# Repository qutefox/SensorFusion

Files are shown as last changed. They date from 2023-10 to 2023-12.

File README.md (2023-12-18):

# Board:
Top | Bottom
--- | ---
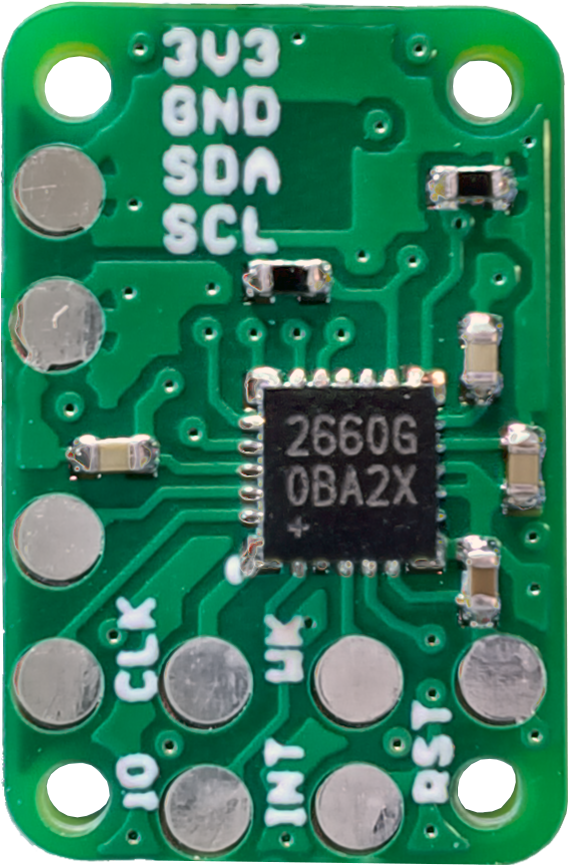
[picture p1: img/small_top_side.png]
Board top side
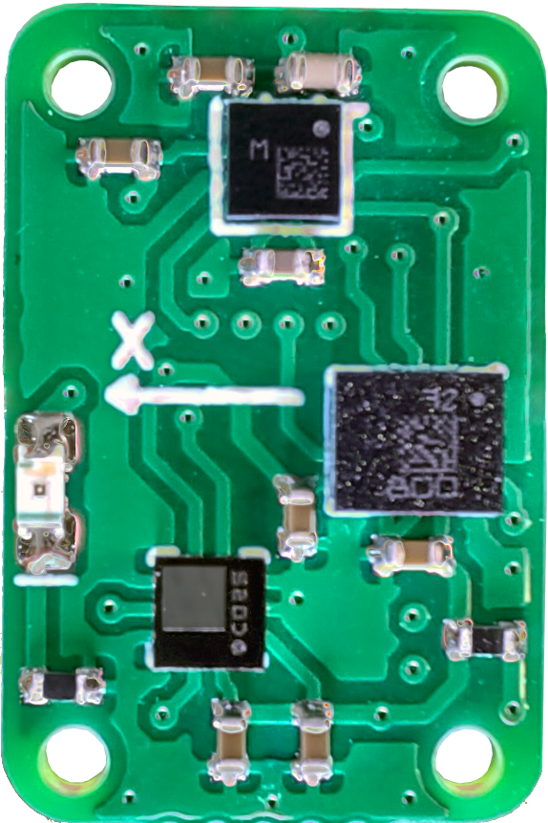
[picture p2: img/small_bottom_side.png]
Board bottom side
 | 

# TODOs:
- calibrate
- host interrupt pin function
- wake pin function
- remove all debug serial print lines and uninit debug serial port
- somehow make automated tests? or at least manual tests with some references
- add some documenatation: register map, usage info

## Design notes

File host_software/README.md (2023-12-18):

# Read out sensor fusion data from host

## Software Prerequisites
- python3

## Hardware Prerequisites
- board with circuitpython (or you can write your own arduino library to use other boards)

## Wiring
Connect your host board to the sensor fusion board via i2c.
Connect your host board to the windows PC via serial (in my case I use the built in circuitpython REPL).

I used Unexpected Maker's PROS3 board (ESP32-S3):

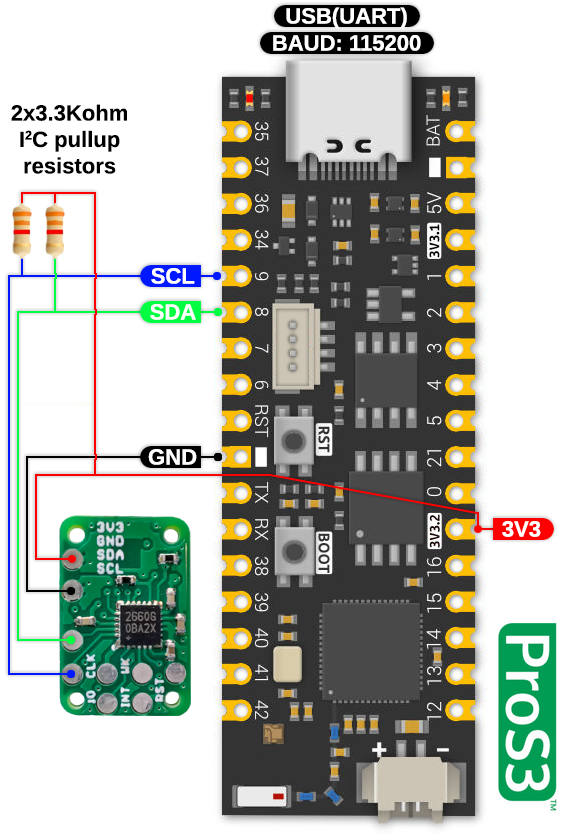
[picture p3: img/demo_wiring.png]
Demo wiring

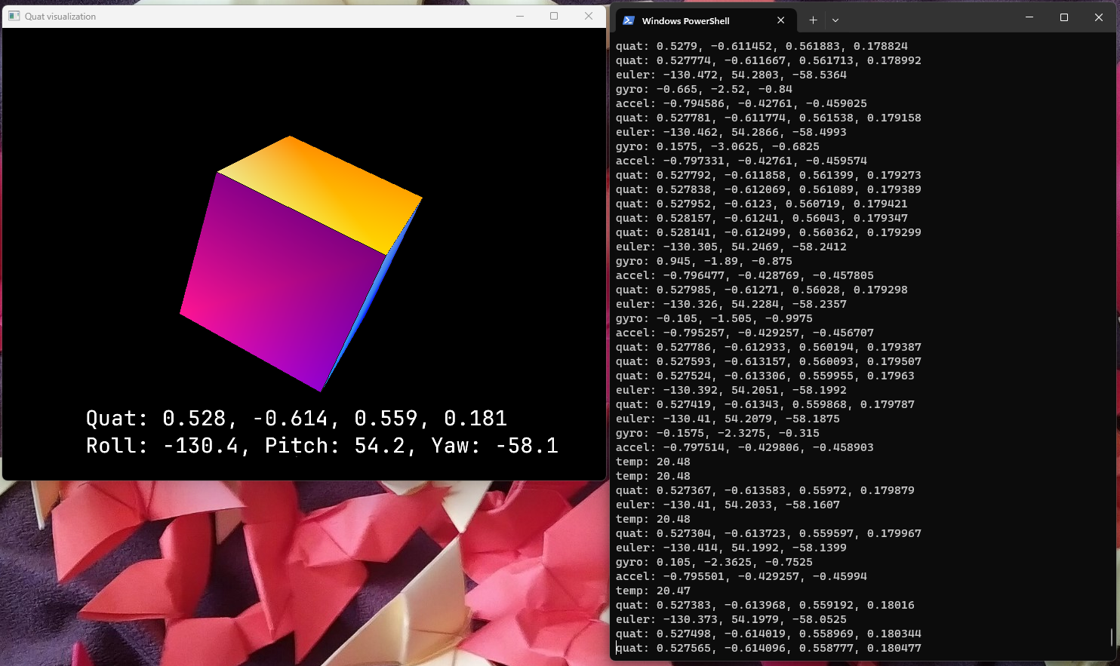
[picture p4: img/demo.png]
Demo


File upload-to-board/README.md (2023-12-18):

# Upload to board

## Software Prerequisites
- python3
- [SEGGER JLink](https://www.segger.com/downloads/jlink/)

## Hardware Prerequisites
- Programmer (Ebay search words: "J-Link OB ARM Debugger Programmer Downloader V8 SWD")
- MAX32660 sensor board
- Jumper wires
- Optional, Serial to USB converter (3.3V) to print out debugging messages

Programmer | Serial to USB 
--- | ---
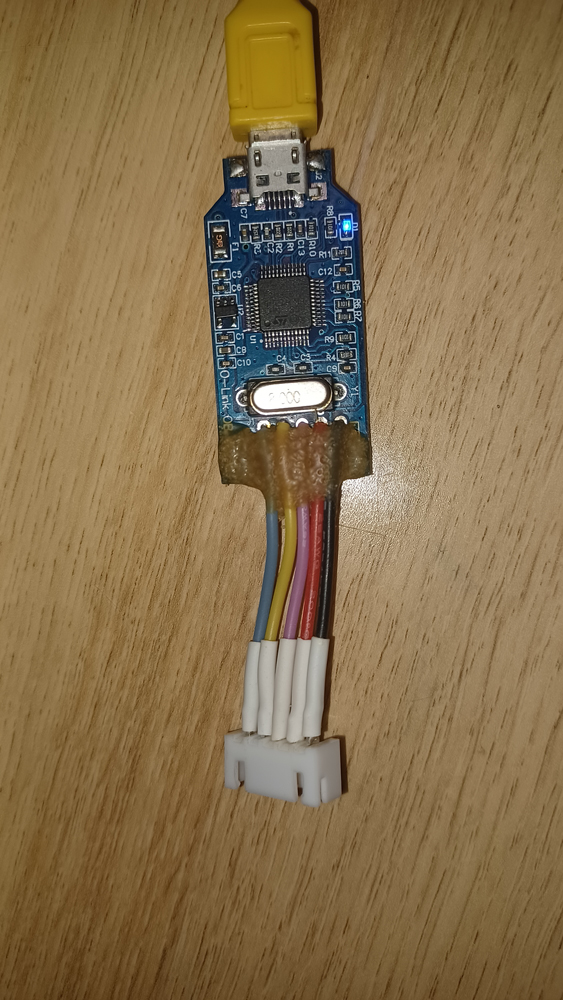
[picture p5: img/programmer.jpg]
Programmer
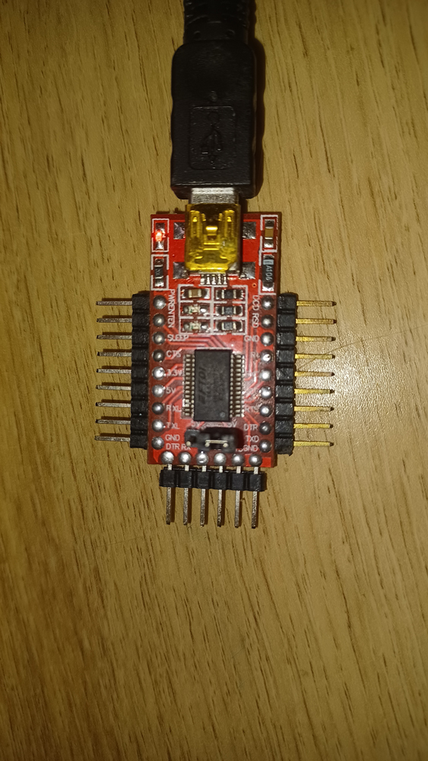
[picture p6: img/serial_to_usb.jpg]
Serial to USB
 | 

Top | Side | Bottom
--- | --- | ---
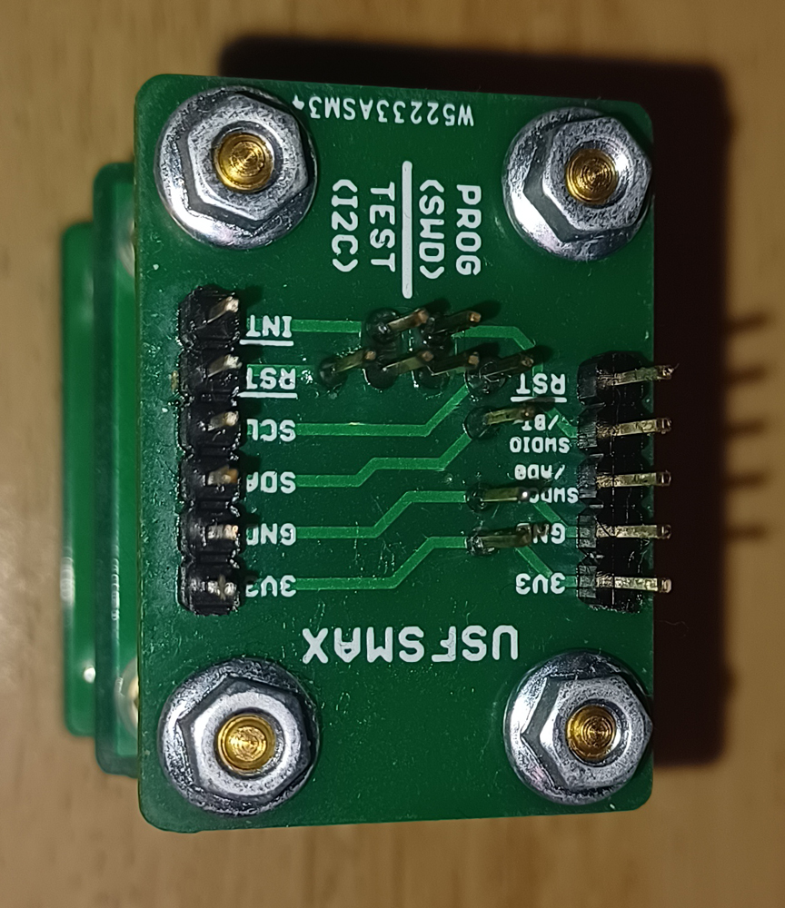
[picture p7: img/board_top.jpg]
Board top
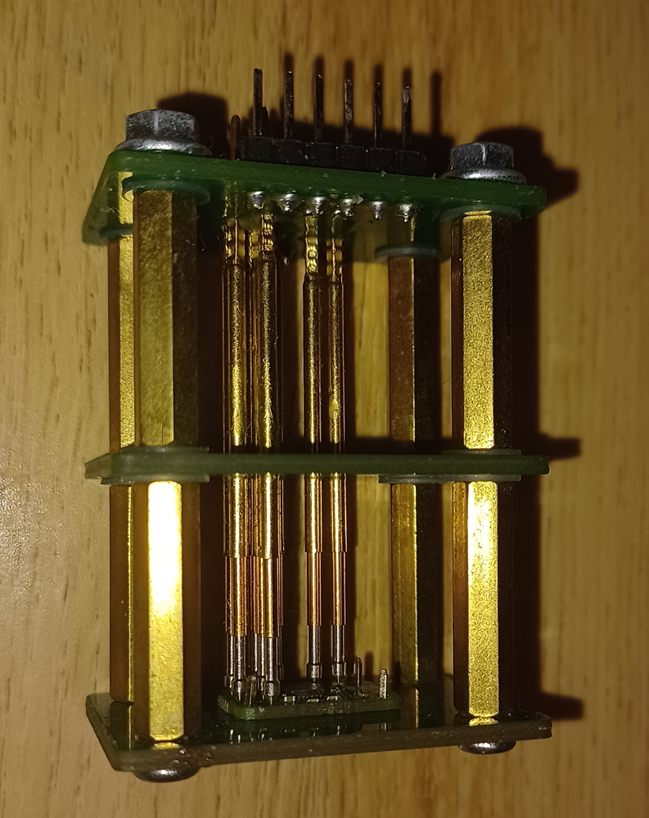
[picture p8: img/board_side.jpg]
Board side
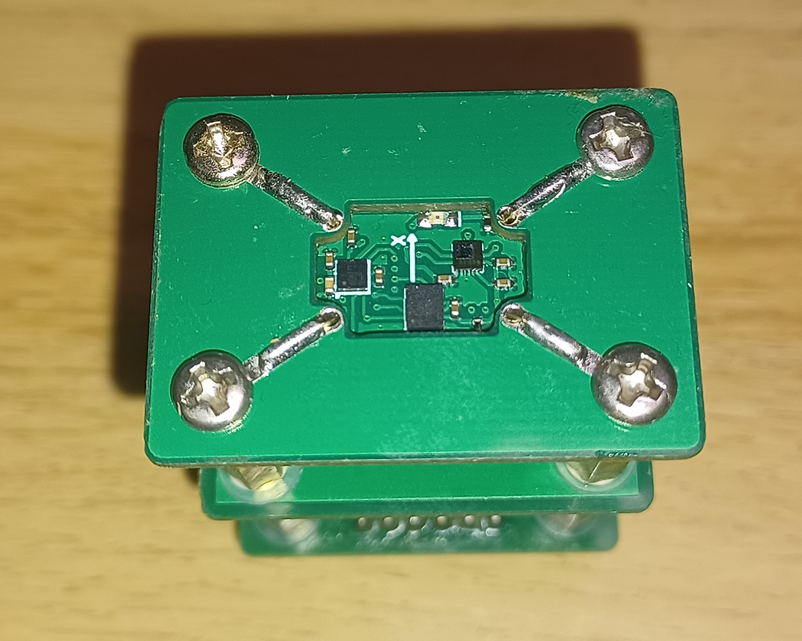
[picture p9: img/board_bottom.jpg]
Board bottom
 |  | 

## Programmer Wiring
Board      | Programmer
-----------|-----------
GND        | GND
3.3V       | 3.3V
SWDCLK/AD0 | SWCLK
SWDIO/BT   | SWDIO
RST        | RST

Programmer setup | Programmer connection | Board connection
--- | --- | ---
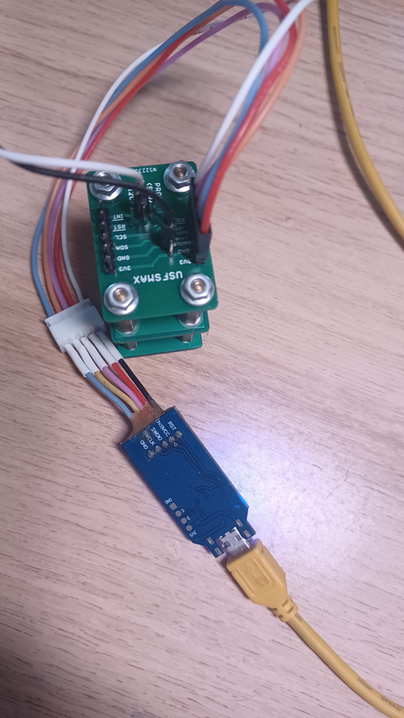
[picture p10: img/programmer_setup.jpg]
Programmer setup
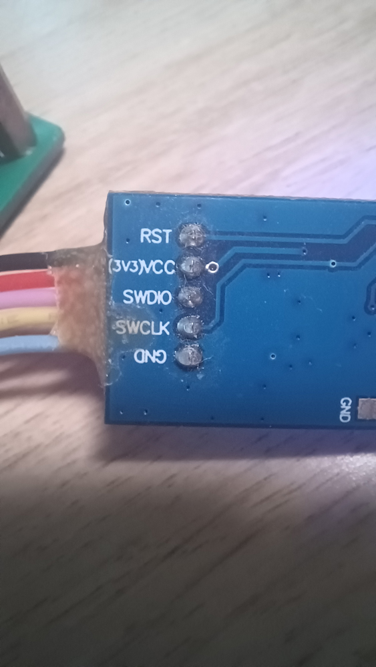
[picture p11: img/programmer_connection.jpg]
Programmer connection
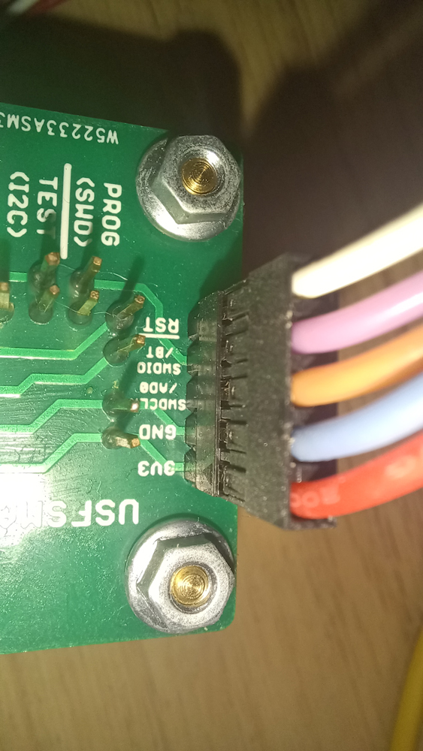
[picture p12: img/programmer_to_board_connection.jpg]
Programmer to board connection
 |  | 

## Serial Wiring (optional)
Board | Serial to USB
------|--------------
GND   | GND
INT   | RX

Serial setup | Serial connection | Board connection
--- | --- | ---
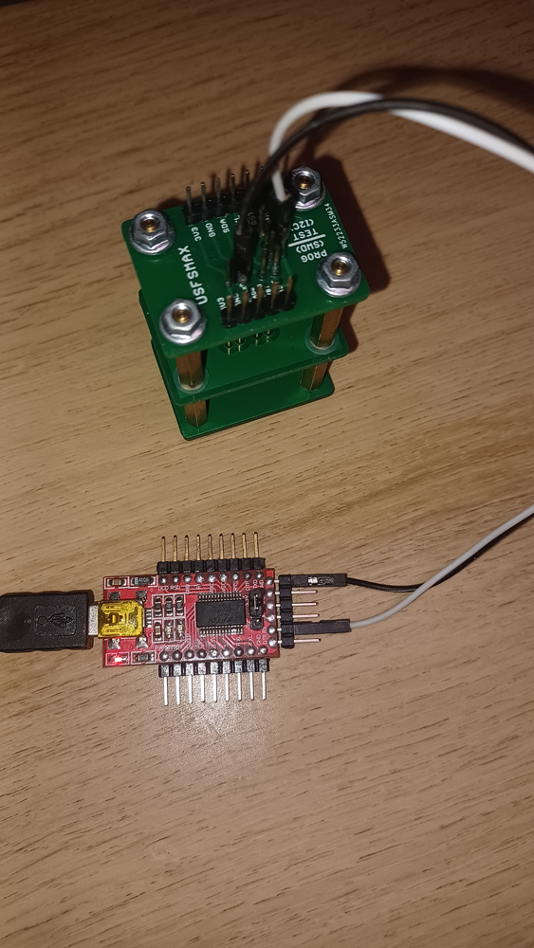
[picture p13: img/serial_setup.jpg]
Serial setup
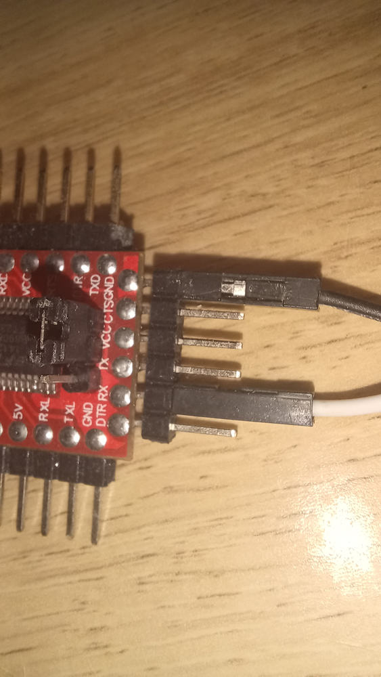
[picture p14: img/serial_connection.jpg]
Serial connection
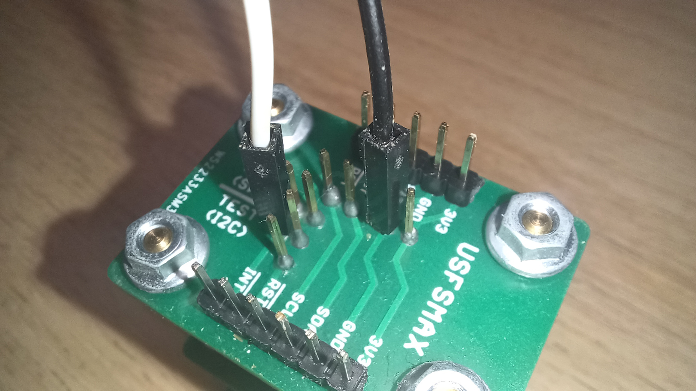
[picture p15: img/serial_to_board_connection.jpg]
Serial to board connection
 |  | 

## Upload
- Wire up the programmer to the board
- Open command line and run command:
```
python path/to/jlink_upload.py
```

## What the script does
- Opens and SWD connection
- Executes commands from file command_file.jlink
	* Uploads the built elf file to the board
	* Resets the board
	* Starts the board
	* Closes the SWD connection

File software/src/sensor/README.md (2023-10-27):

# Sensor driver usage
There are tons of examples on how to use these sensor drivers at https://github.com/STMicroelectronics/STMems_Standard_C_drivers

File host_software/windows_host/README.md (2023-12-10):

# Cube visualisation

To run use command:
```
python windows_host_with_cube_visualisation.py
```

Demo

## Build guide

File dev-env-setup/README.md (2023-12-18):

# Development environment setup guide

For a full guide please visit: https://analog-devices-msdk.github.io/msdk/USERGUIDE/#installation
Further down I will focus on how I setup my own dev environment.

## Visual Studio Code
I use Visual Studio Code as my IDE.
You can download and install it from: https://code.visualstudio.com/download
After completing the Visual Studio Code installation you need to start the IDE and navigate to the extensions.
- Install the [Microsoft C/C++ extension](https://marketplace.visualstudio.com/items?itemName=ms-vscode.cpptools)
- Install the [Cortex-Debug extension](https://marketplace.visualstudio.com/items?itemName=marus25.cortex-debug)
- Later on we will come back and tell Visual Studi Code where we installed the Maxim Micros SDK

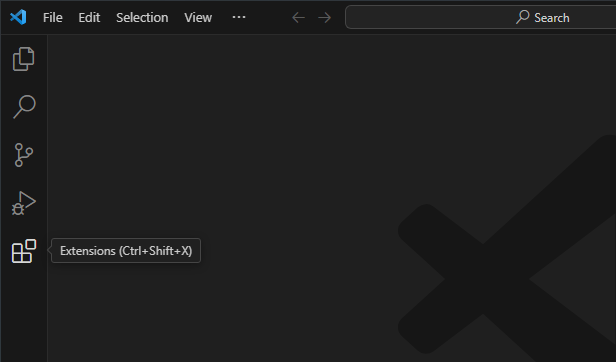
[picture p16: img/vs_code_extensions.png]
Visual Studio Code extensions

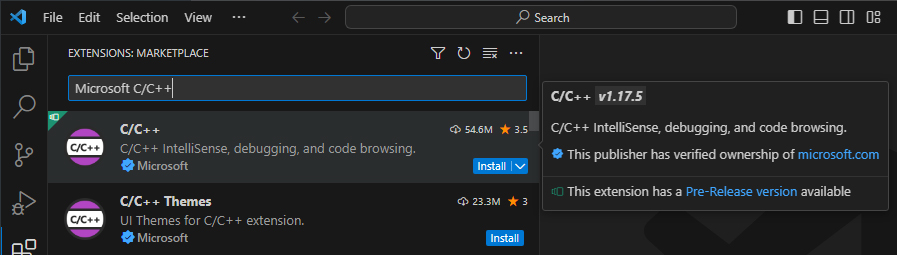
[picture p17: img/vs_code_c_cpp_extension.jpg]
Visual Studio Code C/C++ extension

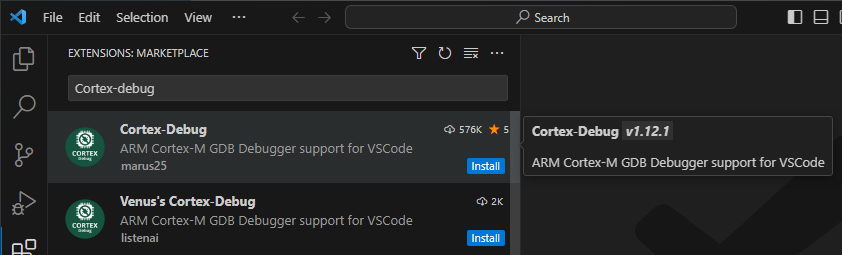
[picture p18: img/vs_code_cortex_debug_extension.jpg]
Visual Studio Code Cortex-Debug extension


## Maxim Micros SDK
You can find documentation, resources, tool, etc.. at: https://www.analog.com/en/products/max32660.html

In the Tools and Simulation section you can find the Maxim Micros SDK download link(s).
Here I give the link to the latest version I can find during writing this guide:
[Maxim Micros SDK (Windows), 1.0.1](https://www.analog.com/en/design-center/evaluation-hardware-and-software/software/software-download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)

During the Maxim Micros SDK (Windows) installation on the component selection screen make sure that "Visual Studio Code Support" is checked.

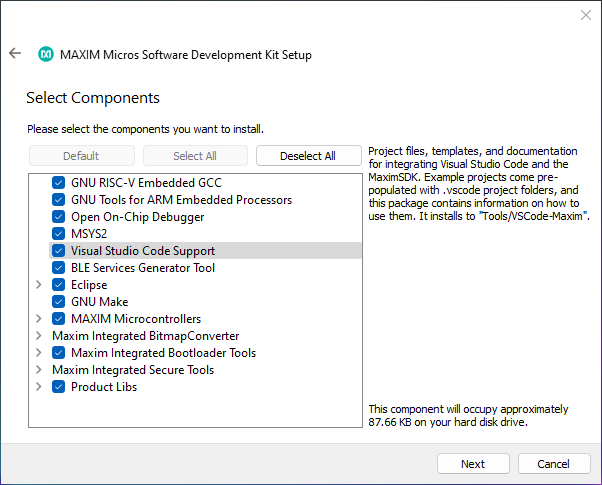
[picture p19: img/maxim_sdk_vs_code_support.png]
Visual Studio Code support


When the installation finishes a popup will appear that will take you to the readme file of the Visual Studio Code Support github page: https://github.com/Analog-Devices-MSDK/VSCode-Maxim/blob/main/README.md

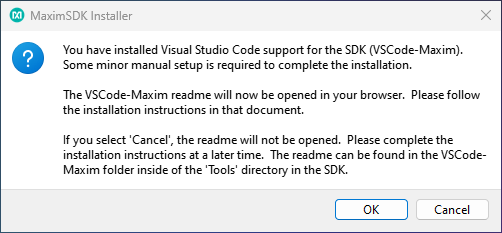
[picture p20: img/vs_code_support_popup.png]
Visual Studio Code support popup


## Setting the "MAXIM_PATH" in your VS Code settings
- Open Visual Studio Code
- Press Ctrl + Shift + P
- In the popup type "Preferences: Open User Settings (JSON)"
- Add a new entry called "MAXIM_PATH" with the path of your MaximSDK installation path. Only use forward slash characters.

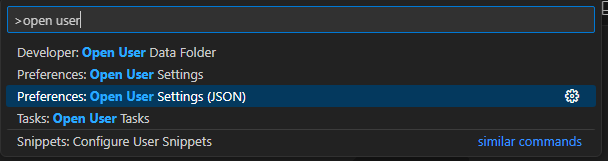
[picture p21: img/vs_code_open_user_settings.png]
Visual Studio Code user settings

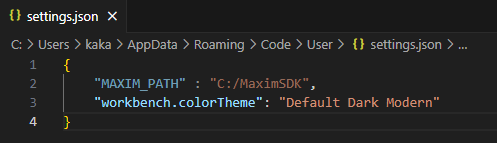
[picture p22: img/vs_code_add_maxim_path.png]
Visual Studio Code maxim path


## How to build
- Open Visual Studio Code
- Open the project
- Press Ctrl + Shift + B
- From the popup select build (or clean and the build).

## How to update the Maxim SDK
You can run the MaintenanceTool.exe which will automatically guide you through the update.

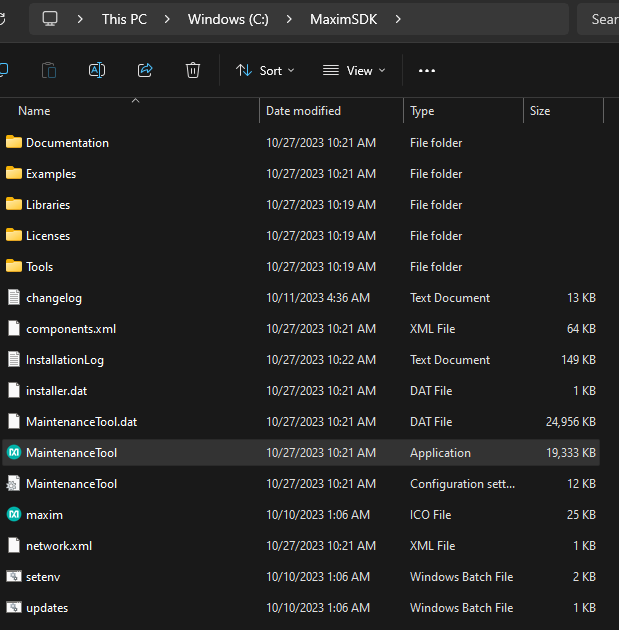
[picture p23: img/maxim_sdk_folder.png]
Maxim Micros SDK Folder


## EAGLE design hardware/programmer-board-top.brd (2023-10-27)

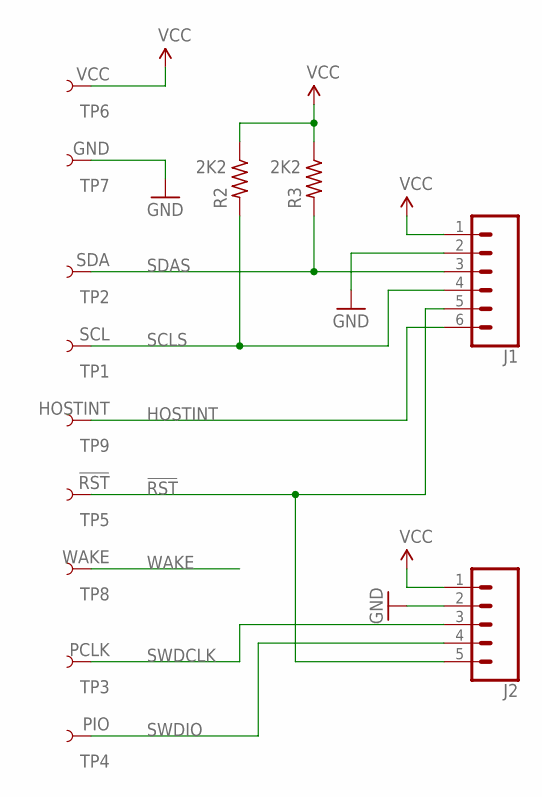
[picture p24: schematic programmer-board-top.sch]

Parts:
J1: CONN_06NO_SILK_FEMALE_PTH; 1X06_NO_SILK
J2: CONN_05NO_SILK; 1X05_NO_SILK
R2, R3: 2K2; R0402_B
TP1: SCL; PAD.03X.06
TP2: SDA; PAD.03X.06
TP3: PCLK; PAD.03X.06
TP4: PIO; PAD.03X.06
TP5: !RST; PAD.03X.06
TP6: VCC; PAD.03X.06
TP7: GND; PAD.03X.06
TP8: WAKE; PAD.03X.06
TP9: HOSTINT; PAD.03X.06

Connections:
!RST: J1.5, J2.5, TP5.1
GND: J1.2, J2.2, TP7.1
HOSTINT: J1.6, TP9.1
SCLS: J1.4, R2.2, TP1.1
SDAS: J1.3, R3.2, TP2.1
SWDCLK: J2.3, TP3.1
SWDIO: J2.4, TP4.1
VCC: J1.1, J2.1, R2.1, R3.1, TP6.1
WAKE: TP8.1

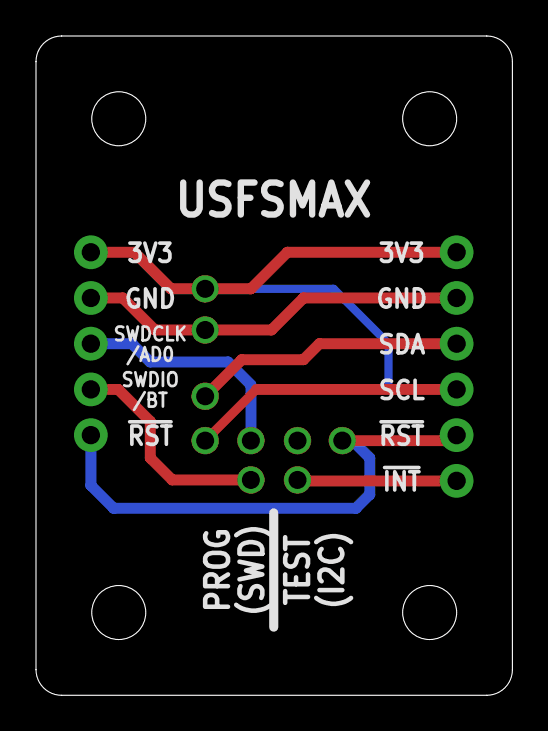
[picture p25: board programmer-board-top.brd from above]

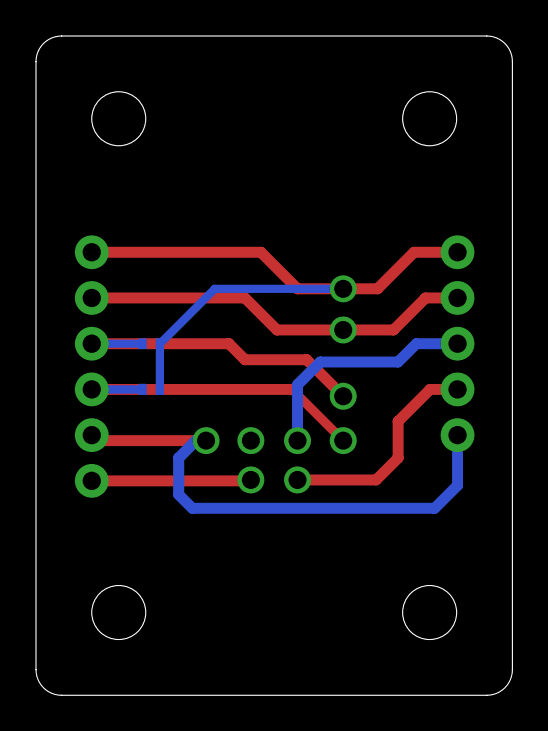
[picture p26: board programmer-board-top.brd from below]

Board: 2 copper layers, 26.5 x 36.6 mm, 13 parts (2 on the bottom side), 8 nets.

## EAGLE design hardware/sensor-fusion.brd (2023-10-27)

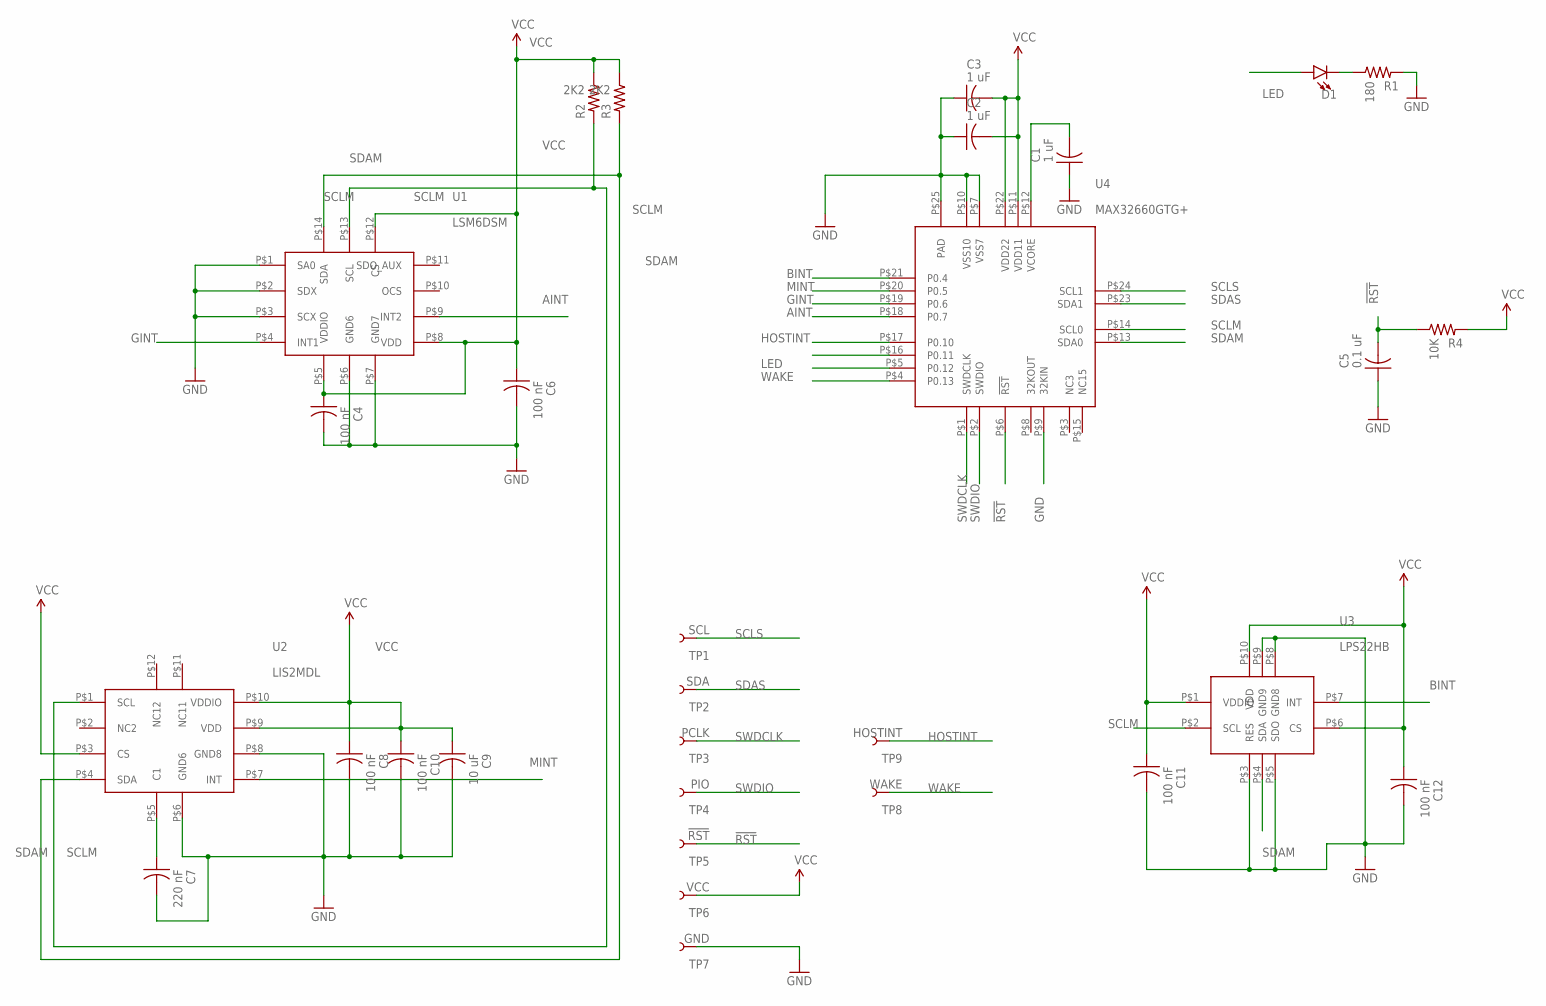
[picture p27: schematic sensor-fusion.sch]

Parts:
C1, C2, C3: 1 uF; C0402_B
C4, C6, C8, C10, C11, C12: 100 nF; C0402_B
C5: 0.1 uF; C0402_B
C7: 220 nF; C0402_B
C9: 10 uF; C0402_B
D1: LED0603; LED-0603
R1: 180; R0402_B
R2, R3: 2K2; R0402_B
R4: 10K; R0402_B
TP1: SCL; PAD.03X.06
TP2: SDA; PAD.03X.06
TP3: PCLK; PAD.03X.06
TP4: PIO; PAD.03X.06
TP5: !RST; PAD.03X.06
TP6: VCC; PAD.03X.06
TP7: GND; PAD.03X.06
TP8: WAKE; PAD.03X.06
TP9: HOSTINT; PAD.03X.06
U1: LSM6DSM
U2: LIS2MDL
U3: LPS22HB
U4: MAX32660GTG+

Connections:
!RST: C5.2, R4.1, TP5.1, U4.P$6 (!RST)
AINT: U1.P$9 (INT2), U4.P$18 (P0.7)
BINT: U3.P$7 (INT), U4.P$21 (P0.4)
GINT: U1.P$4 (INT1), U4.P$19 (P0.6)
GND: C1.1, C2.1, C3.1, C4.2, C5.1, C6.2, C7.2, C8.2, C9.2, C10.2, C11.2, C12.2, R1.2, TP7.1, U1.P$1 (SA0), U1.P$2 (SDX), U1.P$3 (SCX), U1.P$6 (GND6), U1.P$7 (GND7), U2.P$6 (GND6), U2.P$8 (GND8), U3.P$3 (RES), U3.P$5 (SDO), U3.P$8 (GND8), U3.P$9 (GND9), U4.P$7 (VSS7), U4.P$9 (32KIN), U4.P$10 (VSS10), U4.P$25 (PAD)
HOSTINT: TP9.1, U4.P$17 (P0.10)
LED: D1.A, U4.P$5 (P0.12)
MINT: U2.P$7 (INT), U4.P$20 (P0.5)
unnamed: C7.1, U2.P$5 (C1)
unnamed: C1.2, U4.P$12 (VCORE)
unnamed: D1.C, R1.1
OCS: U1.P$10 (OCS)
SCLM: R2.2, U1.P$13 (SCL), U2.P$1 (SCL), U3.P$2 (SCL), U4.P$14 (SCL0)
SCLS: TP1.1, U4.P$24 (SCL1)
SDAM: R3.2, U1.P$14 (SDA), U2.P$4 (SDA), U3.P$4 (SDA), U4.P$13 (SDA0)
SDAS: TP2.1, U4.P$23 (SDA1)
SDO_AUX: U1.P$11 (SDO_AUX)
SWDCLK: TP3.1, U4.P$1 (SWDCLK)
SWDIO: TP4.1, U4.P$2 (SWDIO)
VCC: C2.2, C3.2, C4.1, C6.1, C8.1, C9.1, C10.1, C11.1, C12.1, R2.1, R3.1, R4.2, TP6.1, U1.P$5 (VDDIO), U1.P$8 (VDD), U1.P$12 (CS), U2.P$3 (CS), U2.P$9 (VDD), U2.P$10 (VDDIO), U3.P$1 (VDDIO), U3.P$6 (CS), U3.P$10 (VDD), U4.P$11 (VDD11), U4.P$22 (VDD22)
WAKE: TP8.1, U4.P$4 (P0.13)

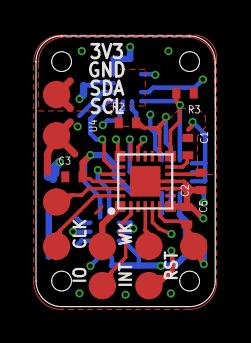
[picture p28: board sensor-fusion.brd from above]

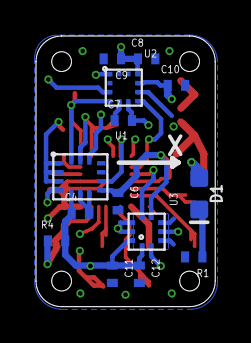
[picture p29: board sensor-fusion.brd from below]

Board: 4 copper layers, 10.0 x 15.0 mm, 30 parts (14 on the bottom side), 19 nets.

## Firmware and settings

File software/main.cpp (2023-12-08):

#include <stdio.h>
#include <exception>

#include "mxc_device.h"
#include "mxc_delay.h"
#include "mxc_errors.h"
#include "lp.h"
#include "uart.h"

#include "src/sensor_fusion_board.h"
#include "src/processor_logic/controller.h"

#include "src/debug_print.h"

// https://analog-devices-msdk.github.io/msdk/Libraries/PeriphDrivers/Documentation/MAX32660/

int main()
{

#ifdef ENABLE_DEBUG_PRINT
    MXC_UART_Init(MXC_UART_GET_UART(CONSOLE_UART), CONSOLE_BAUD, MAP_A);
#endif

	debug_print("\n\nMAX32660 started with debug info.\n");

	SensorFusionBoard* board = SensorFusionBoard::get_instance();

	debug_print("About to init board.\n");

	int board_err = board->begin();
	if (board_err != E_NO_ERROR)
	{
		debug_print("Failed to initialize board: %d.\n", board_err);
	}
	else
	{
		debug_print("Board successfully initialized.\n");
	}

	Controller* controller = Controller::get_instance();

	__enable_irq();

	while (true)
	{
		if (board->can_go_sleep())
		{
			board->prepare_for_sleep();
			MXC_LP_EnterSleepMode();
			// MXC_LP_EnterDeepSleepMode();
		}

		// Handle sensor interrupt(s).
		board->handle_sensor_interrupts();

		// Controller update.
		controller->handle_wakeup();
	}

    return E_NO_ERROR;
}

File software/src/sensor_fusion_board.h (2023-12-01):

#pragma once

#include "mxc_errors.h"

#include "src/storage/flash_interface.h"
#include "src/io/digital_input_pin_interface.h"
#include "src/io/digital_output_pin_interface.h"
#include "src/io/i2c_slave_interface.h"
#include "src/sensor/sensor_interface.h"

#define CONSOLE_UART 1 // UART instance to use for console
#define CONSOLE_BAUD 115200 // Console baud rate

#define I2C_SLAVE 1
#define I2C_SLAVE_SPEED 400000 // 400 kbit/s (aka i2c fast speed)
#define I2C_SLAVE_ADDR 0x51

#define I2C_MASTER 0
#define I2C_MASTER_SPEED 400000 // 400 kbit/s (aka i2c fast speed)
#define I2C_MASTER_CLOCK_STRETCHING 0

#define LPS22HB_I2C_ADDR 0x5C
#define LSM6DSM_I2C_ADDR 0x6A
#define LIS2MDL_I2C_ADDR 0x1E

#define SWDIO_MASK MXC_GPIO_PIN_0 // We only use it after startup. We could use it for something later on.
#define AD0_MASK__SWDCLK_MASK MXC_GPIO_PIN_1 // Free pin after startup. We could use it for something.
#define BARO_INT_MASK MXC_GPIO_PIN_4
#define MAG_INT_MASK MXC_GPIO_PIN_5
#define INERTIAL_INT2_MASK MXC_GPIO_PIN_6
#define INERTIAL_INT1_MASK MXC_GPIO_PIN_7
#define HOSTINT_PIN_MASK MXC_GPIO_PIN_10
#define LED_PIN_MASK MXC_GPIO_PIN_12
#define WAKE_PIN_MASK MXC_GPIO_PIN_13

class SensorFusionBoard
{
private:
    static SensorFusionBoard* instance;
    static uint32_t lock;

    storage::FlashInterface* flash = nullptr;
    io::DigitalOutputPinInterface* led_pin = nullptr;
    io::DigitalOutputPinInterface* host_interrupt_pin = nullptr;
    io::DigitalInputPinInterface* i2c_slave_address_select_pin = nullptr;
    io::DigitalInputPinInterface* barometer_int_pin = nullptr;
    io::DigitalInputPinInterface* inertial_int1_pin = nullptr;
    io::DigitalInputPinInterface* inertial_int2_pin = nullptr;
    io::DigitalInputPinInterface* magnetometer_int_pin = nullptr;
    io::I2cSlaveInterface* i2c_slave = nullptr;
    sensor::SensorInterface* barometer_sensor = nullptr;
    sensor::SensorInterface* inertial_sensor = nullptr;
    sensor::SensorInterface* magnetometer_sensor = nullptr;

    uint8_t get_i2c_slave_address();
    void start_i2c_slave();

protected:
    SensorFusionBoard();
    virtual ~SensorFusionBoard();

public:
    SensorFusionBoard(SensorFusionBoard& other) = delete;
    void operator=(const SensorFusionBoard& other) = delete;

    static SensorFusionBoard* get_instance();

    int begin();

    storage::FlashInterface* get_flash() const { return flash; }
    io::DigitalOutputPinInterface* get_led_pin() const { return led_pin; }
    io::DigitalOutputPinInterface* get_host_interrupt_pin() const { return host_interrupt_pin; }
    io::I2cSlaveInterface* get_i2c_slave() const { return i2c_slave; }
    sensor::SensorInterface* get_barometer_sensor() const { return barometer_sensor; }
    sensor::SensorInterface* get_inertial_sensor() const { return inertial_sensor; }
    sensor::SensorInterface* get_magnetometer_sensor() const { return magnetometer_sensor; }

    bool can_go_sleep();
    void prepare_for_sleep();
    void handle_sensor_interrupts();
};

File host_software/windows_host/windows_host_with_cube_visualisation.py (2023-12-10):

import subprocess, sys

def pipInstall(package):
	subprocess.call([sys.executable, "-m", "pip", "install", package])

try:
	from freetype import *
except ImportError:
	pipInstall("freetype-py")
finally:
	from freetype import *

try:
	import numpy as np
except ImportError:
	pipInstall("numpy")
finally:
	import numpy as np

try:
	import OpenGL.GL as gl
	import OpenGL.GLU as glu
	import OpenGL.GLUT as glut
except ImportError:
	# pip by default fucks this up and installs 32 bit version.
	# However I have 64 bit python installed on my machine.
	# That is why we use pre-downloaded whl.
	# Make sure that the whl matches your python version.
	# For 32 bit python use 32 bit whl.
	pipInstall("PyOpenGL-3.1.6-cp39-cp39-win_amd64.whl")
	pipInstall("PyOpenGL_accelerate-3.1.6-cp39-cp39-win_amd64.whl")
finally:
	import OpenGL.GL as gl
	import OpenGL.GLU as glu
	import OpenGL.GLUT as glut

from serial_reader_thread import SerialReaderThread, Quat

import math

vertices= (
	(1, -1, -1),
	(1, 1, -1),
	(-1, 1, -1),
	(-1, -1, -1),
	(1, -1, 1),
	(1, 1, 1),
	(-1, -1, 1),
	(-1, 1, 1)
)

edges = (
	(0,1),
	(0,3),
	(0,4),
	(2,1),
	(2,3),
	(2,7),
	(6,3),
	(6,4),
	(6,7),
	(5,1),
	(5,4),
	(5,7)
)

surfaces = (
	(0,1,2,3),
	(3,2,7,6),
	(6,7,5,4),
	(4,5,1,0),
	(1,5,7,2),
	(4,0,3,6)
)

colors = (
	(255/255,0/255 ,0/255),  # red
	(255/255,99/255,71/255), # tomato
	(178/255,34/255,34/255), # firebrick
	(220/255,20/255,60/255), # crimson

	(0/255  ,128/255,0/255), # green
	(50/255 ,205/255,50/255), # lime green
	(0/255  ,255/255,127/255), # spring green
	(124/255,252/255,0/255), # lawn green

	(0/255  , 0/255 ,255/255), # blue
	(30/255 ,144/255,255/255), # dodger blue
	(100/255,149/255,237/255), # corn flower blue
	(65/255 ,105/255,225/255), # royal blue

	(255/255,165/255,0/255), # orange
	(255/255,215/255,0/255), # gold
	(240/255,230/255,140/255), # khaki
	(255/255,140/255,0/255), # dark orange

	(139/255,0/255,139/255), # magenta
	(128/255,0/255,128/255), # purple
	(148/255,0/255,211/255), # dark violet
	(255/255,20/255,147/255), # deep pink

	(0/255  ,255/255,255/255), # aqua
	(64/255 ,224/255,208/255), # turquoise
	(127/255,255/255,212/255), # aqua marine
	(0/255  ,206/255,209/255), # dark turquoise
)

class Window():
	def __init__(self, width, height, title):
		self.window = None
		self.base = 0
		self.texid = 0

		glut.glutInit(sys.argv)
		glut.glutInitDisplayMode(glut.GLUT_DOUBLE | glut.GLUT_RGB | glut.GLUT_DEPTH)
		self.window = glut.glutCreateWindow(title)
		glut.glutReshapeWindow(width, height)
		glut.glutDisplayFunc(self.on_display)
		glut.glutReshapeFunc(self.on_reshape)
		glut.glutKeyboardFunc(self.on_keyboard)

		gl.glTexEnvf(gl.GL_TEXTURE_ENV, gl.GL_TEXTURE_ENV_MODE, gl.GL_MODULATE)
		# gl.glEnable(gl.GL_DEPTH_TEST)
		# gl.glEnable(gl.GL_BLEND)
		gl.glEnable(gl.GL_COLOR_MATERIAL)
		gl.glColorMaterial(gl.GL_FRONT_AND_BACK, gl.GL_AMBIENT_AND_DIFFUSE)
		gl.glBlendFunc(gl.GL_SRC_ALPHA, gl.GL_ONE_MINUS_SRC_ALPHA)
		gl.glEnable(gl.GL_TEXTURE_2D)

		gl.glShadeModel(gl.GL_SMOOTH)
		gl.glClearColor(0, 0, 0, 0)
		gl.glClearDepth(1)
		gl.glEnable(gl.GL_DEPTH_TEST)
		gl.glDepthFunc(gl.GL_LEQUAL)
		gl.glHint(gl.GL_PERSPECTIVE_CORRECTION_HINT, gl.GL_NICEST)

		self.make_font("JetBrainsMono-Medium.ttf", 64)

		self.serial = SerialReaderThread()
		self.serial.start()

		glut.glutTimerFunc(25, self.timer_event, 1)

		glut.glutMainLoop()

	def __del__(self):
		if self.window is not None:
			glut.glutDestroyWindow(self.window)
			self.window = None
		self.serial.stopped = True
		self.serial.join()

	def timer_event(self, value):
		glut.glutPostRedisplay()
		glut.glutTimerFunc(25, self.timer_event, 1)

	def make_font(self, filename, size):
		# Load font  and check it is monotype
		face = Face(filename)
		face.set_char_size( size*64 )
		if not face.is_fixed_width:
			raise 'Font is not monotype'

		# Determine largest glyph size
		width, height, ascender, descender = 0, 0, 0, 0
		for c in range(32,128):
			face.load_char(chr(c), FT_LOAD_RENDER | FT_LOAD_FORCE_AUTOHINT)
			bitmap	= face.glyph.bitmap
			width	 = max( width, bitmap.width )
			ascender  = max( ascender, face.glyph.bitmap_top )
			descender = max( descender, bitmap.rows-face.glyph.bitmap_top )
		height = ascender+descender

		# Generate texture data
		Z = np.zeros((height*6, width*16), dtype=np.ubyte)
		for j in range(6):
			for i in range(16):
				face.load_char(chr(32+j*16+i), FT_LOAD_RENDER | FT_LOAD_FORCE_AUTOHINT)
				bitmap = face.glyph.bitmap
				x = i*width  + face.glyph.bitmap_left
				y = j*height + ascender - face.glyph.bitmap_top
				Z[y:y+bitmap.rows,x:x+bitmap.width].flat = bitmap.buffer

		# Bound texture
		self.texid = gl.glGenTextures(1)
		gl.glBindTexture(gl.GL_TEXTURE_2D, self.texid)
		gl.glTexParameterf(gl.GL_TEXTURE_2D, gl.GL_TEXTURE_MAG_FILTER, gl.GL_LINEAR)
		gl.glTexParameterf(gl.GL_TEXTURE_2D, gl.GL_TEXTURE_MIN_FILTER, gl.GL_LINEAR)
		gl.glTexImage2D(gl.GL_TEXTURE_2D, 0, gl.GL_ALPHA, Z.shape[1], Z.shape[0], 0,
						gl.GL_ALPHA, gl.GL_UNSIGNED_BYTE, Z)

		# Generate display lists
		dx, dy = width/float(Z.shape[1]), height/float(Z.shape[0])
		self.base = gl.glGenLists(8*16)
		for i in range(8*16):
			c = chr(i)
			x = i%16
			y = i//16-2
			gl.glNewList(self.base+i, gl.GL_COMPILE)
			if (c == '\n'):
				gl.glPopMatrix()
				gl.glTranslatef( 0, -height, 0)
				gl.glPushMatrix()
			elif (c == '\t'):
				gl.glTranslatef(4*width, 0, 0)
			elif (i >= 32):
				gl.glBegin(gl.GL_QUADS)
				gl.glTexCoord2f((x  )*dx, (y+1)*dy), gl.glVertex(0,	 -height)
				gl.glTexCoord2f((x  )*dx, (y  )*dy), gl.glVertex(0,	 0 )
				gl.glTexCoord2f((x+1)*dx, (y  )*dy), gl.glVertex(width, 0 )
				gl.glTexCoord2f((x+1)*dx, (y+1)*dy), gl.glVertex(width, -height)
				gl.glEnd()
				gl.glTranslatef(width, 0, 0)
			gl.glEndList()

	def draw_text(self, text, x, y):
		gl.glEnable(gl.GL_BLEND)
		gl.glBindTexture(gl.GL_TEXTURE_2D, self.texid)
		gl.glColor(1,1,1,1) # white
		gl.glPushMatrix()
		gl.glTranslate(x, y, -5)
		gl.glPushMatrix()
		gl.glScalef(0.003, 0.003, 0.003)
		gl.glListBase(self.base)
		gl.glCallLists([ord(c) for c in text])
		gl.glPopMatrix()
		gl.glPopMatrix()
		gl.glBindTexture(gl.GL_TEXTURE_2D, 0)
		gl.glDisable(gl.GL_BLEND)

	def draw_cube_lines(self):
		gl.glBegin(gl.GL_LINES)
		gl.glColor3fv((0.1,0.1,0.1))
		for edge in edges:
			for vertex in edge:
				gl.glVertex3iv(vertices[vertex])
		gl.glEnd()

	def draw_cube_surfaces(self):
		gl.glBegin(gl.GL_QUADS)
		x = 0
		for surface in surfaces:
			for vertex in surface:
				gl.glColor3fv(colors[x])
				x+=1
				gl.glVertex3fv(vertices[vertex])
		gl.glEnd()

	def on_display(self):
		gl.glClearColor(0,0,0,0)
		gl.glClear(gl.GL_COLOR_BUFFER_BIT | gl.GL_DEPTH_BUFFER_BIT)

		gl.glLoadIdentity()
		gl.glTranslatef(0, 0, -7.0) # zoom out
		q = self.serial.quat
		degrees = 2 * math.acos(q.w) * 180.00/math.pi
		gl.glRotatef(degrees, -1 * q.nx, q.nz, q.ny)
		self.draw_cube_lines()
		self.draw_cube_surfaces()
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

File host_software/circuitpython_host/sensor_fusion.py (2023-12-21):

import time
import ulab.numpy as np
from micropython import const
from adafruit_bus_device.i2c_device import I2CDevice

CTRL1_REG_ADDR                = const(0x00)
CTRL2_REG_ADDR                = const(0x01)
STAT_REG_ADDR                 = const(0x02)
PM_REG_ADDR                   = const(0x03)
DRDY_REG_ADDR                 = const(0x04)

QUAT_DATA_REG_ADDR            = const(0x05)
QUAT_DATA_REG_LEN             = const(4*4)

EULER_DATA_REG_ADDR           = const(QUAT_DATA_REG_ADDR + QUAT_DATA_REG_LEN)
EULER_DATA_REG_LEN            = const(3*4)

EARTH_DATA_REG_ADDR           = const(EULER_DATA_REG_ADDR + EULER_DATA_REG_LEN)
EARTH_DATA_REG_LEN            = const(3*4)

GYRO_DATA_REG_ADDR            = const(EARTH_DATA_REG_ADDR + EARTH_DATA_REG_LEN)
GYRO_DATA_REG_LEN             = const(3*4)

ACCEL_DATA_REG_ADDR           = const(GYRO_DATA_REG_ADDR + GYRO_DATA_REG_LEN)
ACCEL_DATA_REG_LEN            = const(3*4)

MAG_DATA_REG_ADDR             = const(ACCEL_DATA_REG_ADDR + ACCEL_DATA_REG_LEN)
MAG_DATA_REG_LEN              = const(3*4)

PRESSURE_DATA_REG_ADDR        = const(MAG_DATA_REG_ADDR + MAG_DATA_REG_LEN)
PRESSURE_DATA_REG_LEN         = const(3)

TEMP_DATA_REG_ADDR            = const(PRESSURE_DATA_REG_ADDR + PRESSURE_DATA_REG_LEN)
TEMP_DATA_REG_LEN             = const(2)

GYRO_MISALIGNMENT_REG_ADDR    = const(TEMP_DATA_REG_ADDR + TEMP_DATA_REG_LEN)
GYRO_MISALIGNMENT_REG_LEN     = const(9*4)

GYRO_SENSITIVITY_REG_ADDR     = const(GYRO_MISALIGNMENT_REG_ADDR + GYRO_MISALIGNMENT_REG_LEN)
GYRO_SENSITIVITY_REG_LEN      = const(3*4)

GYRO_OFFSET_REG_ADDR          = const(GYRO_SENSITIVITY_REG_ADDR + GYRO_SENSITIVITY_REG_LEN)
GYRO_OFFSET_REG_LEN           = const(3*4)

ACCEL_MISALIGNMENT_REG_ADDR   = const(GYRO_OFFSET_REG_ADDR + GYRO_OFFSET_REG_LEN)
ACCEL_MISALIGNMENT_REG_LEN    = const(9*4)

ACCEL_SENSITIVITY_REG_ADDR    = const(ACCEL_MISALIGNMENT_REG_ADDR + ACCEL_MISALIGNMENT_REG_LEN)
ACCEL_SENSITIVITY_REG_LEN     = const(3*4)

ACCEL_OFFSET_REG_ADDR         = const(ACCEL_SENSITIVITY_REG_ADDR + ACCEL_SENSITIVITY_REG_LEN)
ACCEL_OFFSET_REG_LEN          = const(3*4)

SOFT_IRON_MATRIX_REG_ADDR     = const(ACCEL_OFFSET_REG_ADDR + ACCEL_OFFSET_REG_LEN)
SOFT_IRON_MATRIX_REG_LEN      = const(9*4)

HARD_IRON_OFFSET_REG_ADDR     = const(SOFT_IRON_MATRIX_REG_ADDR + SOFT_IRON_MATRIX_REG_LEN)
HARD_IRON_OFFSET_REG_LEN      = const(3*4)

CTRL1_REG_EULER_MASK           = const(0x01)
CTRL1_REG_EARTH_MASK           = const(0x02)
CTRL1_REG_LED_MASK             = const(0x80)

CTRL2_REG_FUSION_START_MASK    = const(0x01)
CTRL2_REG_FUSION_STOP_MASK     = const(0x02)
CTRL2_REG_CALIB_START_MASK     = const(0x04)
CTRL2_REG_CALIB_STOP_MASK      = const(0x08)
CTRL2_REG_CALIB_CANCEL_MASK    = const(0x10)
CTRL2_REG_CALIB_RESET_MASK     = const(0x20)
CTRL2_REG_CALIB_ACTIVE_MASK    = const(0x40)
CTRL2_REG_SW_RESTART_MASK      = const(0x80)

STAT_REG_FUSION_RUNNING_MASK  = const(0x01)
STAT_REG_CALIB_UPLOADING_MASK = const(0x02)
STAT_REG_GYRO_ERROR_MASK      = const(0x10)
STAT_REG_ACCEL_ERROR_MASK     = const(0x20)
STAT_REG_MAG_ERROR_MASK       = const(0x40)
STAT_REG_BARO_ERROR_MASK      = const(0x80)
STAT_REG_ERRORS_MASK          = const(0xF0)

# PM_REG_GYRO_MASK            = const(0x03)
# PM_REG_ACCEL_MASK           = const(0x0C)
# PM_REG_MAG_MASK             = const(0x30)
# PM_REG_BARO_MASK            = const(0xC0)

DRDY_REG_QUAT_MASK            = const(0x01)
DRDY_REG_EULER_MASK           = const(0x02)
DRDY_REG_EARTH_MASK           = const(0x04)
DRDY_REG_GYRO_MASK            = const(0x08)
DRDY_REG_ACCEL_MASK           = const(0x10)
DRDY_REG_MAG_MASK             = const(0x20)
DRDY_REG_BARO_MASK            = const(0x40)
DRDY_REG_TEMP_MASK            = const(0x80)

class InertialCalibrationData():
    def __init__(self):
        self.misalignment = np.zeros((3,3), dtype=np.float)
        self.sensitivity = np.zeros((3), dtype=np.float)
        self.offset = np.zeros((3), dtype=np.float)

    def parse_from_buffer(self, buff:bytearray):
        arr = np.frombuffer(buff, dtype=np.float)
        self.misalignment = np.array(arr[0:9], dtype=np.float).reshape((3,3))
        self.sensitivity = np.array(arr[9:12], dtype=np.float)
        self.offset = np.array(arr[12:15], dtype=np.float)

    def to_bytearray(self):
        arr = self.misalignment.tobytes()
        arr.extend(self.sensitivity.tobytes())
        arr.extend(self.offset.tobytes())
        return arr

    def __str__(self):
        out =  f"misalignment:\n{self.misalignment}\n"
        out += f"sensitivity:\n{self.sensitivity}\n"
        out += f"offset:\n{self.offset}\n"
        return out

class MagCalibrationData():
    def __init__(self):
        self.soft_iron_matrix = np.zeros((3,3), dtype=np.float)
        self.hard_iron_offset = np.zeros((3), dtype=np.float)

    def parse_from_buffer(self, buff:bytearray):
        arr = np.frombuffer(buff, dtype=np.float)
        self.soft_iron_matrix = np.array(arr[0:9], dtype=np.float).reshape((3,3))
        self.hard_iron_offset = np.array(arr[9:12], dtype=np.float)

    def to_bytearray(self):
        arr = self.soft_iron_matrix.tobytes()
        arr.extend(self.hard_iron_offset.tobytes())
        return arr

    def __str__(self):
        out =  f"soft iron matrix:\n{self.soft_iron_matrix}\n"
        out += f"hard iron offset:\n{self.hard_iron_offset}\n"
        return out

class CalibrationData():
    def __init__(self):
        self.gyro = InertialCalibrationData()
        self.accel = InertialCalibrationData()
        self.mag = MagCalibrationData()

    def __str__(self):
        out =  f"gyro:\n{str(self.gyro)}\n"
        out += f"accel:\n{str(self.accel)}\n"
        out += f"mag:\n{str(self.mag)}\n"
        return out
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

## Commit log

2023-10-27 Added sensor driver submodules
2023-10-27 Added eagle CAD files.
    [programmer-board-bottom.brd, programmer-board-bottom.sch, programmer-board-middle.brd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]
2023-10-27 LPS22HB barometric sensor first steps.
2023-10-27 Adding in "dirty" sensor drivers.
2023-10-28 Split pinio into input_pin and ouput pin. Input pin received "attach_interrupt_callback" method.
2023-10-28 Added back (forked and fixed) submodule repos.
    [lps22hb.cpp]
2023-10-28 Added basic register map for i2c slave memory area.
2023-10-29 Added i2c slave component. Rewrote existing components to follow singleton pattern.
2023-10-29 First round of i2c slave fixes. Register writing seems to work. Reading causes error where we immediately go to transaction close event. Needs more troubleshooting.
    [i2c_master.cpp, i2c_slave.cpp, i2c_slave.h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]
2023-10-29 Fixed i2c slave mode.
    [i2c_slave.cpp, i2c_slave.h, lps22hb.cpp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]
2023-10-30 Improved i2c slave: main thread no longer has to continuously poll the state and start the next async task. The interrupt handler will automatically do this. Added register map reader writer class to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
    [i2c_slave.cpp, i2c_slave.h, main.cpp]
2023-11-02 Rewritten register handling and register map init code because previous version was hard to expand/change. Any (new) register change (insert ot the middle of the map) required to move the address of 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
2023-11-03 Added sleep/wakeup for main thread.
2023-11-03 Added sensor interface. Added some initial lsm6dsm gyro/accel sensor code.
2023-11-04 Inertial sensor module is now running in FIFO mode. Added power mode selection to the sensor interface.
2023-11-05 Added magnetic sensor init code.
2023-11-05 Data processor interface improvement to receive all sensor data.
2023-11-06 This is the time when I realise sensors should not use FIFO :) This is also the time when I realise the fusion algorythm requires delta time and the RTC functionality will only work on the MCU if the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
    [input_pin.cpp, lis2mdl.cpp, lps22hb.cpp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]
2023-11-11 [IMPROVEMENT] Rewrite the sensor codes to not use fifo. Added interface classes to most of the components. Current code is to test the lsm6dsm timestamp feature.
2023-11-17 [FIX] Finally understood that reading sensor data inside interrupts is a bad idea and causes a system "crash" becuase multiple i2c communications overlap. I2c master debug variable was always overwri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
    [digital_input_pin.cpp, i2c_device.cpp, i2c_master.cpp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]
2023-11-25 [IMPROVEMENT] Added flash read, write to store calibration configuration in the future. Fixed initialise codes. Simplified interfaces.
    [i2c_slave.cpp, lis2mdl.cpp, lps22hb.cpp]
2023-11-25 [FIX] Sensor fusion start/stop bit was a bad design, because after handling the start bit, we clear out the flag. Writing zero to that flag did not trigger a change event afterwards. Separated the 1 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
    [lsm6dsm.cpp, main.cpp, register_fields.h]
2023-12-01 [IMPROVEMENT] Added calibration data. Reworked register map. Fixed i2c slave bus off recovery. Separated data processor into controller and fusion data modules.
    [fusion_data.h]
2023-12-08 [FIX] Fixed sensor units and made test code for Circuitpython host MCU. Also made a python tool for windows to read the circuitpython host via serial port and visualise the quaterion data with a cube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
    [code.py, fusion_data.h]
2023-12-11 [FIX] Setting power mode in circuitpython host library was wrong. Caused to power down sensors. Also there is something wrong with the high performance mode in the inertial sensor. Will have too look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
    [code.py, lis2mdl.cpp, lps22hb.cpp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]
2023-12-18 Flipped board bottom side image to match the top side image of the board.
2023-12-21 [FIX] Missed i2c pullup resistors from wiring diagram. Typo fixes.
    [sensor_fusion.py]

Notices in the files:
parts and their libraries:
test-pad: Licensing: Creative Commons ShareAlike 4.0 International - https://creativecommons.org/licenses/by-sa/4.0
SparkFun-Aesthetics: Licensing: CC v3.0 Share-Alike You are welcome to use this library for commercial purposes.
